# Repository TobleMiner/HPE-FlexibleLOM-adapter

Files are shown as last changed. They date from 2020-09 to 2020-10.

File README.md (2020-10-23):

HPE FlexibleLOM to PCIe adapter
===============================

This PCB is an adapter that allows using HPE FlexibleLOM cards in normal
PCIe x8 slots.

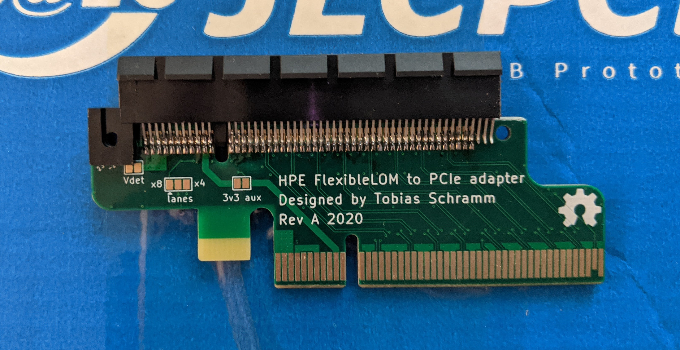
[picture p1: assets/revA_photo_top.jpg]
PCB top


# Ordering

Make sure to order this PCB with ENIG finish and beveled edges. Else contact
might be poor or your PCIe slots could be damaged.  
When ordering through JLC I'd recommend enabling the "Impedance" option and
sticking to the default JLC7628 stackup during ordering.

# Assembly

The board requires just a stradle mount PCIe x8 connector to be fitted.
You can get it at LCSC: [C404097](https://lcsc.com/product-detail/Card-Edge-Connectors_UMAX-3126-10102T_C404097.html)

# Mechanical mounting

This board has been designed to bring the front FlexibleLOM mounting hole as
close as possible to the PCIe bracket retention screw on a full size PCIe slot.
You can use a small angled metal piece or a even a 3d printed one to mount the
card into place.

# Jumpers

This adapter cards has several jumpers. You should not need to touch them, however
the following sections will explain their purpose.

## PERST

This jumper selects where the PCIe reset signal is routed. By default it is routed
to A1 on the FlexibleLOM slot. I believe this to be the PCIe reset signal. However,
there is also another pin on the connector, A14 which behaves similarly to A1.  
Testing has shown that the cards does not always enumerate properly when using A14
as PCIe reset.  
The two resistor footprints next to this jumper can be populated in case you are
having issues with floating resets on the cards resulting in spurious resets. I
have not encountered any such issues.

## Vdet

The Vdet jumper bridges +12V to pin B1 on the FlexibleLOM slot. I assume B1 to be
some sort of voltage detection pin since it is routed very differently from all
other +12V power signals on the card.

## 3v3 aux

The 3v3 aux jumper connects what I think is the auxiliary 3v3 volt voltage supply
on the FlexibleLOM slot to the auxiliary 3v3 supply of the PCIe connector. Most
cards I've seen do not use this voltage rail. However I assume there might be some
that utilize it for WOL capability.

## lanes

This jumper controls which PRSNT2 pin is bridged to PRSNT1. It defaults to PRSNT2
for 8x cards since that is the maximum number of lanes on a FlexibleLOM slot. You
can try setting this jumper to 4x if you are having issues with card detection.  
However, a lot of modern devices tend to ignore the PRSNT2 line and rely solely on
detecting the lane transmitters/receivers. Thus this setting will be irrelevant for
most devices.

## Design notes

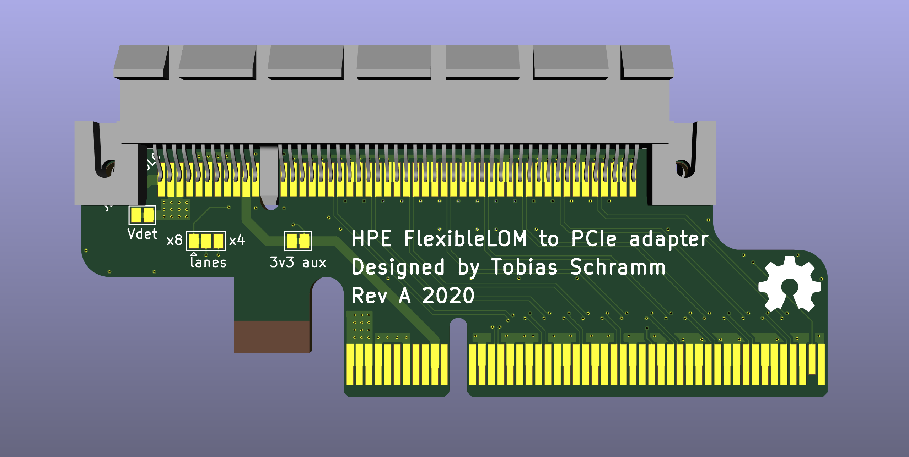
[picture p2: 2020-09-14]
assets/HPE_FlexibleLOM_adapter_x8_top.png

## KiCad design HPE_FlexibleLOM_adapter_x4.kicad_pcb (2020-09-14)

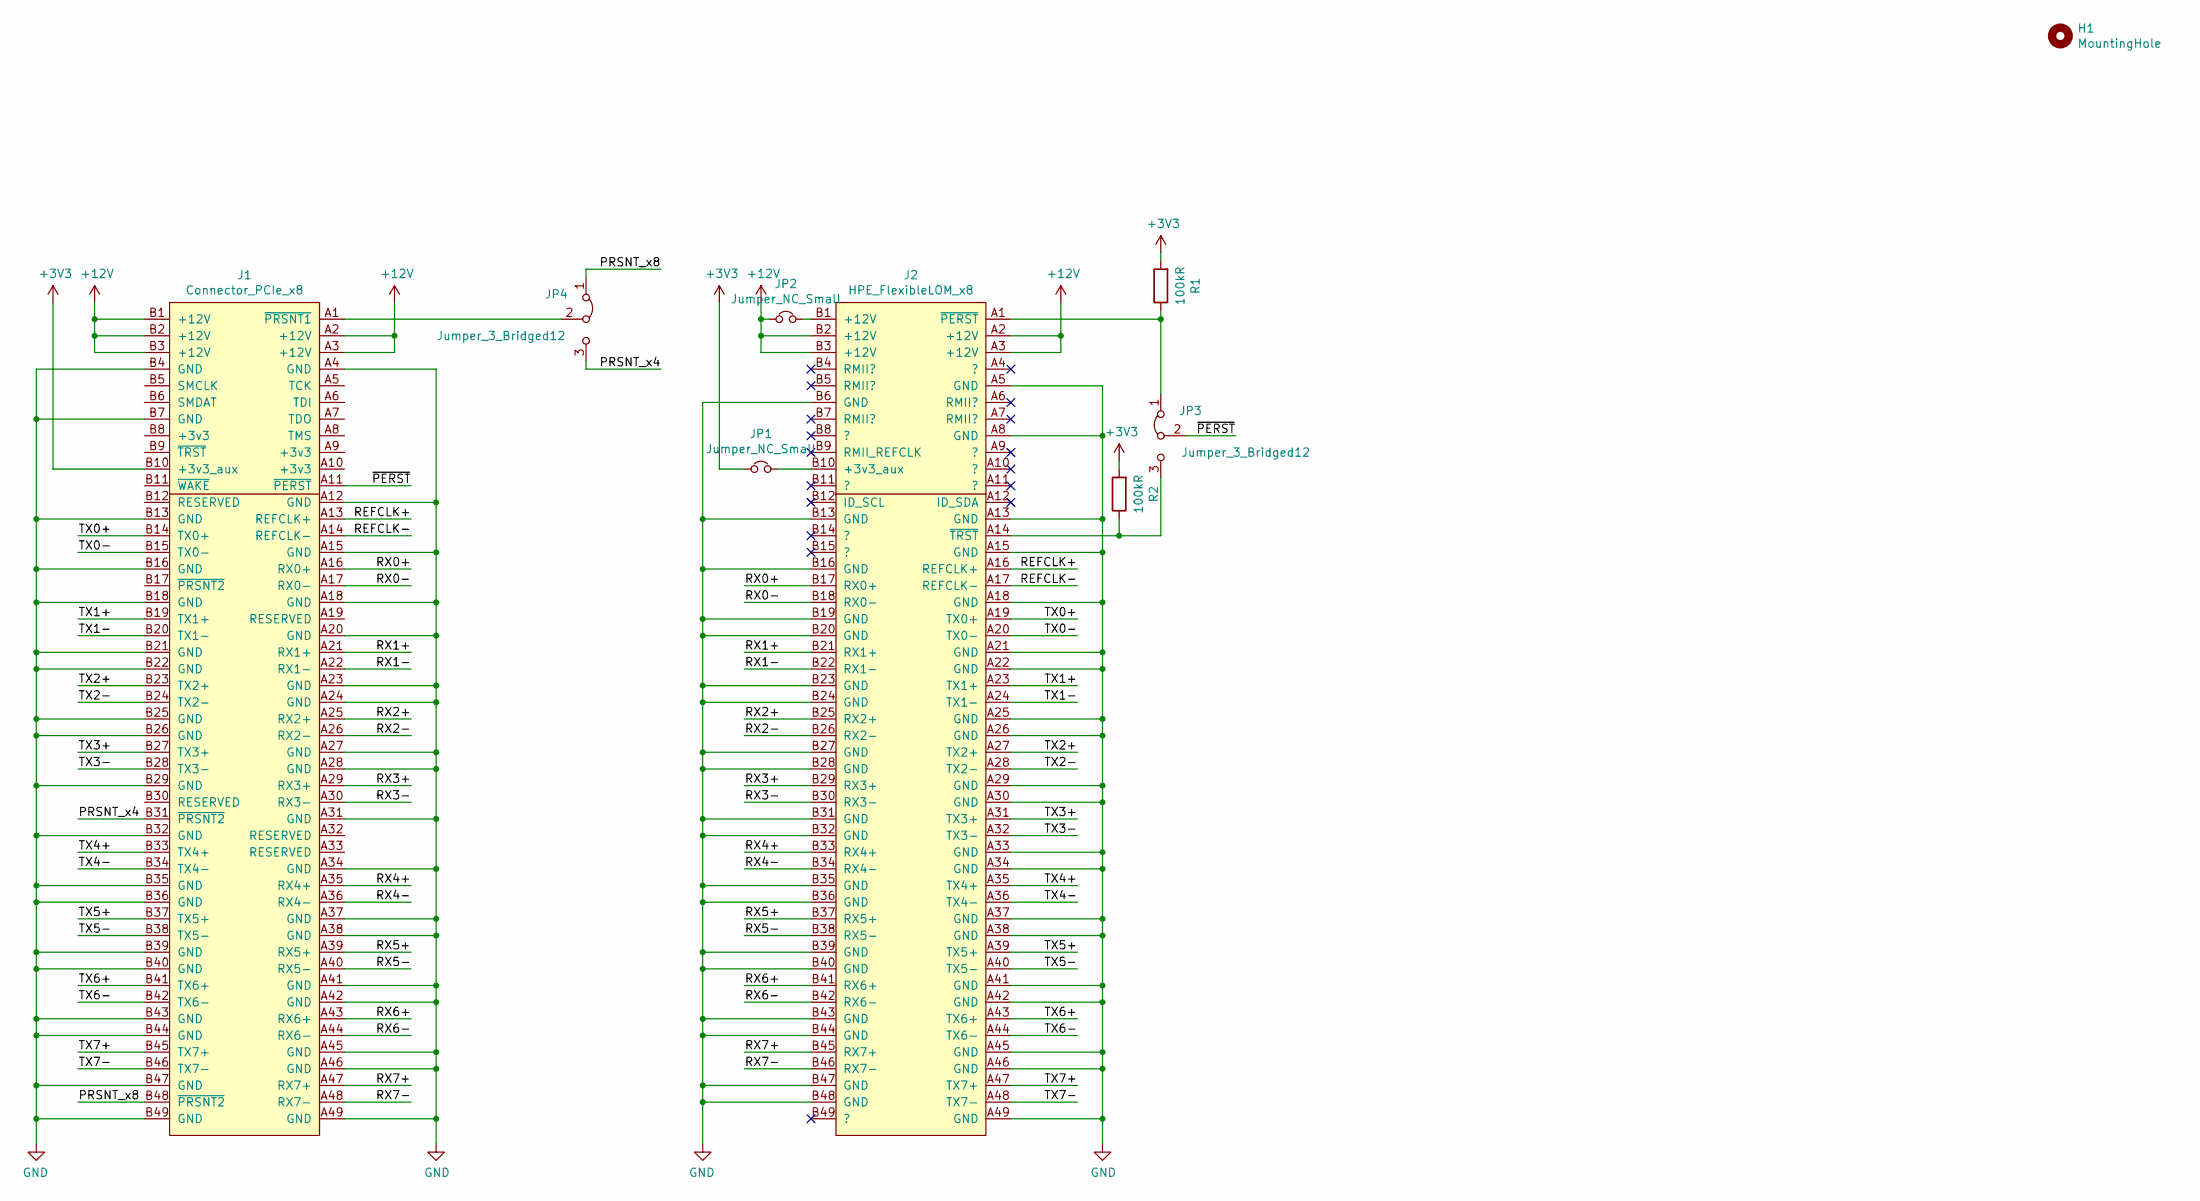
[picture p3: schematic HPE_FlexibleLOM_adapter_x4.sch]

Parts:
H1: MountingHole; OSHW-Symbol_6.7x6mm_SilkScreen
J1: Connector_PCIe_x8; BUS_PCIexpress_x8
J2: HPE_FlexibleLOM_x8; UMAX_3126-10102T_PCIe_x8_edge_launch
JP1, JP2: Jumper_NC_Small; SolderJumper-2_P1.3mm_Bridged_Pad1.0x1.5mm
JP3, JP4: Jumper_3_Bridged12; SolderJumper-3_P1.3mm_Bridged12_Pad1.0x1.5mm
R1, R2: 100kR; R_0402_1005Metric

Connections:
+3V3: J1.B10 (+3v3_aux), JP1.1, R1.2, R2.2
+12V: J1.A2 (+12V), J1.A3 (+12V), J1.B1 (+12V), J1.B2 (+12V), J1.B3 (+12V), J2.A2 (+12V), J2.A3 (+12V), J2.B2 (+12V), J2.B3 (+12V), JP2.1
/PRSNT_x4: J1.B31 (~PRSNT2), JP4.3 (B)
/PRSNT_x8: J1.B48 (~PRSNT2), JP4.1 (A)
/REFCLK+: J1.A13 (REFCLK+), J2.A16 (REFCLK+)
/REFCLK-: J1.A14 (REFCLK-), J2.A17 (REFCLK-)
/RX0+: J1.A16 (RX0+), J2.B17 (RX0+)
/RX0-: J1.A17 (RX0-), J2.B18 (RX0-)
/RX1+: J1.A21 (RX1+), J2.B21 (RX1+)
/RX1-: J1.A22 (RX1-), J2.B22 (RX1-)
/RX2+: J1.A25 (RX2+), J2.B25 (RX2+)
/RX2-: J1.A26 (RX2-), J2.B26 (RX2-)
/RX3+: J1.A29 (RX3+), J2.B29 (RX3+)
/RX3-: J1.A30 (RX3-), J2.B30 (RX3-)
/RX4+: J1.A35 (RX4+), J2.B33 (RX4+)
/RX4-: J1.A36 (RX4-), J2.B34 (RX4-)
/RX5+: J1.A39 (RX5+), J2.B37 (RX5+)
/RX5-: J1.A40 (RX5-), J2.B38 (RX5-)
/RX6+: J1.A43 (RX6+), J2.B41 (RX6+)
/RX6-: J1.A44 (RX6-), J2.B42 (RX6-)
/RX7+: J1.A47 (RX7+), J2.B45 (RX7+)
/RX7-: J1.A48 (RX7-), J2.B46 (RX7-)
/TX0+: J1.B14 (TX0+), J2.A19 (TX0+)
/TX0-: J1.B15 (TX0-), J2.A20 (TX0-)
/TX1+: J1.B19 (TX1+), J2.A23 (TX1+)
/TX1-: J1.B20 (TX1-), J2.A24 (TX1-)
/TX2+: J1.B23 (TX2+), J2.A27 (TX2+)
/TX2-: J1.B24 (TX2-), J2.A28 (TX2-)
/TX3+: J1.B27 (TX3+), J2.A31 (TX3+)
/TX3-: J1.B28 (TX3-), J2.A32 (TX3-)
/TX4+: J1.B33 (TX4+), J2.A35 (TX4+)
/TX4-: J1.B34 (TX4-), J2.A36 (TX4-)
/TX5+: J1.B37 (TX5+), J2.A39 (TX5+)
/TX5-: J1.B38 (TX5-), J2.A40 (TX5-)
/TX6+: J1.B41 (TX6+), J2.A43 (TX6+)
/TX6-: J1.B42 (TX6-), J2.A44 (TX6-)
/TX7+: J1.B45 (TX7+), J2.A47 (TX7+)
/TX7-: J1.B46 (TX7-), J2.A48 (TX7-)
/~PERST: J1.A11 (~PERST), JP3.2 (C)
GND: J1.A4 (GND), J1.A12 (GND), J1.A15 (GND), J1.A18 (GND), J1.A20 (GND), J1.A23 (GND), J1.A24 (GND), J1.A27 (GND), J1.A28 (GND), J1.A31 (GND), J1.A34 (GND), J1.A37 (GND), J1.A38 (GND), J1.A41 (GND), J1.A42 (GND), J1.A45 (GND), J1.A46 (GND), J1.A49 (GND), J1.B4 (GND), J1.B7 (GND), J1.B13 (GND), J1.B16 (GND), J1.B18 (GND), J1.B21 (GND), J1.B22 (GND), J1.B25 (GND), J1.B26 (GND), J1.B29 (GND), J1.B32 (GND), J1.B35 (GND), J1.B36 (GND), J1.B39 (GND), J1.B40 (GND), J1.B43 (GND), J1.B44 (GND), J1.B47 (GND), J1.B49 (GND), J2.A5 (GND), J2.A8 (GND), J2.A13 (GND), J2.A15 (GND), J2.A18 (GND), J2.A21 (GND), J2.A22 (GND), J2.A25 (GND), J2.A26 (GND), J2.A29 (GND), J2.A30 (GND), J2.A33 (GND), J2.A34 (GND), J2.A37 (GND), J2.A38 (GND), J2.A41 (GND), J2.A42 (GND), J2.A45 (GND), J2.A46 (GND), J2.A49 (GND), J2.B6 (GND), J2.B13 (GND), J2.B16 (GND), J2.B19 (GND), J2.B20 (GND), J2.B23 (GND), J2.B24 (GND), J2.B27 (GND), J2.B28 (GND), J2.B31 (GND), J2.B32 (GND), J2.B35 (GND), J2.B36 (GND), J2.B39 (GND), J2.B40 (GND), J2.B43 (GND), J2.B44 (GND), J2.B47 (GND), J2.B48 (GND)
unnamed: J1.A1 (~PRSNT1), JP4.2 (C)
unnamed: J2.A1 (~PERST), JP3.1 (A), R1.1
unnamed: J2.A14 (~TRST), JP3.3 (B), R2.1
unnamed: J2.B1 (+12V), JP2.2
unnamed: J2.B10 (+3v3_aux), JP1.2

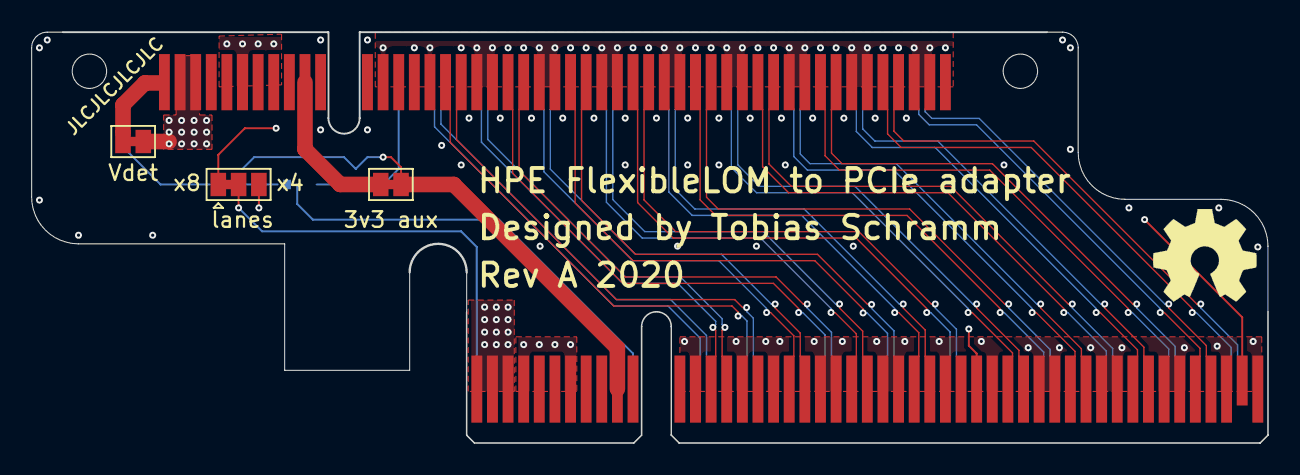
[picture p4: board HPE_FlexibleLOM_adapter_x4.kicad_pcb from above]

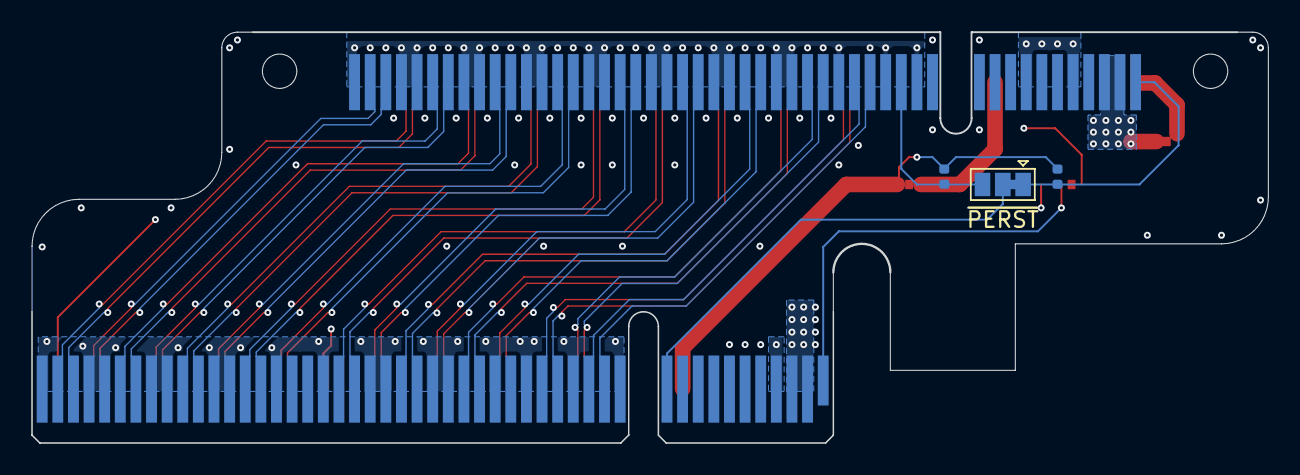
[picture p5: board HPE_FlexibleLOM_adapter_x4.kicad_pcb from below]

Board: 4 copper layers, 79.2 x 26.3 mm, 9 parts (3 on the bottom side), 45 nets.

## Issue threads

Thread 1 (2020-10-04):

JLCPCB caan not produce the chamfered edges

MarcSN311, 2020-10-04:
I just tried to order the PCBs from JLCPCB. They wont produce the chamfered edges because the minimum required board size for the chaamfer is 50mm.
Maybe you should add that to the Readme to make the ordering process smoother.

DanielG, 2020-10-04:
I also ordered some boards from JLC just now, but they seem to have accepted them for production without a hitch. Though you are right, their [docs](https://jlcpcb.com//quote/pcbOrderFaq/Gold%20Fingers) say "3. A board with a size of smaller than 5x5cm will be too small to be beveled.". Weird.

TobleMiner, 2020-10-04:
Interesting. I did not run into that issue.
I could panelize the boards, connecting two at the long non-beveled side. IIRC they can bevel opposing edges.

TobleMiner, 2020-10-04:
@MarcSN311
I've panelized two of the boards. Feel free to try uploading this file to JLC:
[fab_panel.zip](https://github.com/TobleMiner/HPE-FlexibleLOM-adapter/files/5323663/fab_panel.zip)

MarcSN311, 2020-10-04:
@DanielG they accepted my production files as well but then reached out to me to tell me they could not do it.
@TobleMiner Thanks, i'll give it a try.

TobleMiner, 2020-10-05:
@MarcSN311 Did JLC approve the files yet? I'd love to update the repo with a panelized version.

footlongC, 2020-10-07:
> @MarcSN311 Did JLC approve the files yet? I'd love to update the repo with a panelized version.

I was able to get an order in and approved yesterday. Shows in production now.

MarcSN311, 2020-10-07:
Sorry I'm a bit slow. I will inform you as soon as my production files are confirmed.

TobleMiner, 2020-10-08:
No worries. I'm not in a hurry. Just want to make sure you are keeping us all up to date :smile:

psc24, 2020-10-09:
I've had fab_panel.zip rejected because it had too many files; I assume this is the embedded fab_panel directory. Having removed that from the zip it seems to have been accepted.

neobenedict, 2020-10-13:
I was able to order revA.zip quantity 10 pieces without issue. It might be you weren't ordering a large enough quantity.

psc24, 2020-10-13:
Nope, I ordered 10 off as well. Based on experience so far, I think it's just as likely that there's little consistency in the checks JLC perform!

Hi Sir/ Madam, there are too many files in your zip file and we don’t know which file we should use, so could you please delete useless files in your Zip file?You can click ‘Replace file’ button to re-upload the file in your JLCPCB account page .Thanks.

TobleMiner, 2020-10-17:
Oops, the subdirectory is not supposed to be in that zip file. I've updated the zip file above again (actually final this time, I promise!) so JLC won't be confused by it anymore.

MarcSN311, 2020-10-20:
Just received my order!
I had the same problem with the duplicate files, but they did not complain about the chamfered edges anymore.
Sadly they did not produce the chamfered edges anyways -.-

neobenedict, 2020-10-20:
Same thing here, no chamfers, is it an issue?

MarcSN311, 2020-10-20:
I think the chafers are just nicer to your PCIe slots. I am just annoyed by thefact that they exchanged a bunch of messages with me about the chafer and in the end they did not produce it anyways.

laf0rge, 2020-10-21:
Indeed, the production run JLC did for me also silently disregarded the chamfered edges. I think with careful insertion into the slots it shouldn't be that much of a problem.  Aside from that, there's always the option to file the edges by hand, but FR4 dust is also not particularly healthy, to say the least...

kontakt, 2020-10-23:
I ordered 5x of the latest and got received 4, one did not survive fab. May be related to difficulty in chamfering.

MarcSN311, 2020-10-23:
@kontakt were the remaining 4 PCBs chamfered?

kontakt, 2020-10-23:
Yes, the four I received were chamfered.

TobleMiner, 2020-10-23:
@neobenedict It is not a particularly big issue. However it makes insertion easier and increases the lifetime of the PCIe slot.

jbaznik, 2020-12-31:
Is this order HPE FlexibleLOM to PCIe adapter from https://cart.jlcpcb.com by your notes for ordering:

[cart.jlcpcb.com-PCB Prototype amp PCB Fabrication Manufacturer - order - HPE-FlexibleLOM-adapter.pdf](https://github.com/TobleMiner/HPE-FlexibleLOM-adapter/files/5757713/cart.jlcpcb.com-PCB.Prototype.amp.PCB.Fabrication.Manufacturer.-.order.-.HPE-FlexibleLOM-adapter.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)

TobleMiner, 2021-01-01:
Other than that I'd suggest selecting "Specify a location"at the bottom of the page this order looks correctly configured to me.

the1cyrus, 2021-02-16:
How much did your order of 10 cost you? I'm trying to use oshpark

TobleMiner, 2021-02-16:
Depends on whether you want 10 boards or 10 adapters, since there are 2 adapters per board. With edge chamfer and ENIG the prices at JLC are:

5 boards: $20
10 boards: $25

Most of the price is a one-time fee for surface finish and edge chamfer.

the1cyrus, 2021-02-16:
> 10 boards or 10 adapters

The difference between the two are what? The gerber files you upload on the site? Boards are fab_panel.zip and adapters are revA.zip?

I tried uploading the fab_panel.zip and got a quote for $29.20 (qty 10) with the settings are shown on the pdf from jbaznik. That sound right or should i upload revA.zip and do the same settings from jbaznik?

TobleMiner, 2021-02-17:
Yes, the panel contains two adapter boards each. However, getting the panel made costs the same as ordering just single boards.

$29 sounds about right? Does that price include shipping? My previous numbers were probably e bit off since I guesstimated them from  Euros.

the1cyrus, 2021-02-17:
So the grand total is $44 with fab_panel.zip. The boards were $29 and shipping with Fedex was $15. I added gold fingers to try and reduce some oxidation over time but that was probably not needed (i didn't see a price increase with that option).  TobleMiner do you have a way to contact you outside this github issue?

TobleMiner, 2021-02-18:
@the1cyrus Sure, feel free to write me either DMs on Twitter (https://twitter.com/Toble_Miner) or contact me by E-Mail: tobleminer(at)gmail(dot)com

the1cyrus, 2021-02-18:
Just fyi for everyone.. JLCPCB charged me an extra $25 because I used the paneled boards (fab_panel.zip).
"Hi Sir/Madam,the special price is only for the single board and not for the panel board,so you may need to pay for an extra cost for it."

TobleMiner, 2021-02-18:
Unfortunately review is very inconsistent at JLC. This kind of stuff seems to depend heavily on who exactly reviews your gerber files. Not that I'd recommend this, but sometimes just cancelling the order and resubmitting it might work wonders.

CNC-at-Home, 2021-09-10:
Hi together, I've a question please, I ordered some of the pcbs from sysmocom.de and then I attached it with the LAN-Card (it's a HPE FlexFabric 10Gb 2-port 533FLR-T)  into the motherboard, but no reaction from Windows 10. Maybe is there a need to set jumpers or should it works out of the box, only soldering the pins. I've a second card for my Linux Server, but I will wait to build in until my question is answered. Thank you

Greetings
Olli

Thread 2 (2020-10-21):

extend Readme

MarcSN311, 2020-10-21:
Hi,
would be great if you could extend the readme a little bit.

From my limited testing I think the host PCIe slot needs to provide 3.3V, can you confirm that?

Could you describe in which cases the jumpers need to be changed?

TobleMiner, 2020-10-23:
Hi,

sure. I'm very open to ideas regarding a better README.

I'm not sure if the cards require 3.3V. On one of the SFP+ models I have the 3.3v rail is not connected to anything on the board. Might be that other cards need it though.

The jumpers were mostly there in case I messed up during reverse engineering.

I'll add a section to the README explaining what the different jumpers do.

MarcSN311, 2020-10-23:
I had one of the Mellanox ConnectX-3 single port SFP+ cards lying around. I just measured and found the 3.3V Rail is connected to a bunch of caps on the board.

A list of tested card with their requirements might be another useful addition to the Readme (or maybe the wiki?).

TobleMiner, 2020-10-23:
Think 8cc9fc21a973bd5b9cdf8be47b14b1373eb9ac02 should make this a lot clearer

TobleMiner, 2020-10-23:
@MarcSN311
> I just measured and found the 3.3V Rail is connected to a bunch of caps on the board.
Yeah, nvm. Did not remember this correctly. The 3v3 aux are connected on my card, too. Guess it might be to keep connectivity via NC-SI even when +12V is missing?

MarcSN311, 2020-10-25:
Thanks for the Readme update! I think this resolves the issue for me.

Closed 2020-10-25.

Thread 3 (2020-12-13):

Adapter confirmed working with HP 561FLR-T - we might want a compatibility list?

Aterfax, 2020-12-13:
I have installed a HP 701525-001 ETHERNET 10GB 2-PORT 561FLR-T ADAPTER 700699-B21 700697-001 today into my Windows 10 Machine and confirmed basic functions are working fully.

I may eventually do some performance testing but this is my only 10GB card installed so far.

Drivers can be downloaded here:  https://support.hpe.com/hpsc/swd/public/detail?swItemId=MTX_a3bc42166be146aea4156a05a9

Unzip the exe with 7zip into a folder, then update drivers on the below and point at the folder.

Screenshots below:
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

logan2611, 2020-12-27:
I can also confirm that these adapters (mostly) work with the 561FLR-T. Linux' ixgbe driver works with these out of the box.
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
I was able to get 9.38 Gb/s with iperf.

I'm not sure if I have defective ones or if the adapter isn't fully compatible but I have a few that do not work with various issues. Two don't have power and one hangs the BIOS during boot time. Most of them however work fine.

Aterfax, 2021-03-20:
Seems that the ixgbe driver may have issues as I cannot get connectivity over the 2nd ethernet port under Proxmox - this appears to be fine in Windows 10.

NishaYume, 2021-04-05:
Thats nice, im thinking to try it. Is the model 700699-B21 you tested with the rev a?

Aterfax, 2021-04-05:
>
>
> Seems that the ixgbe driver may have issues as I cannot get connectivity over the 2nd ethernet port under Proxmox - this appears to be fine in Windows 10.

I resolved this issue - Proxmox wasn't setting things on the CLI despite being set in the GUI.

All my adaptors are they rev a.

templehasfallen, 2021-06-18:
> I'm not sure if I have defective ones or if the adapter isn't fully compatible but I have a few that do not work with various issues. Two don't have power and one hangs the BIOS during boot time. Most of them however work fine.

I'm having a similar issue - only 3 out of 11 of my 561FLR-T cards seem to be working with the rev.A adapter - the others are not detected at all.

I cannot find any real differences between the cards, they seem to be identical. Also the cards heat up to the same degree as the working ones.

Any ideas?

LimesKey, 2023-09-28:
Works for me too! Thank you for the driver link, I spent way too long looking through HP’s website. Now time to try to use it on Linux…

jimmycaille, 2023-10-05:
I have just purchased one on Ebay.
I will let you know how it works for me on a more recent Asus x570-pro and Windows 10 (if I don't forget...).
The listing is "701525-001 700699-B21 700697-001" So I don't know wich one I will get...

_To be continued_

Pet0203, 2023-10-08:
Also running a 701525-001. Interestingly it prevents my Dell T3600 from booting but it runs fine and gets detected in a newer machine. Very weird how it doesn't want to boot, while the card is getting power and link lamps turn on.

wildboyfire, 2023-11-07:
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

Hi, i did the same exact thing and i use x570 platform too but i can't get it to work. The 10Gbe card only gets recognised as ethernet controller in device manager, under other devices, only when i turn off the psu for a while and then start it up as normal.When i reboot the system the card will not show up in device manager. When i install the drivers (when it gets recognised) the card will vanish from device manager. Any suggestions?

Aterfax, 2023-11-07:
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

A hot boot causing issues suggests the machine might not be "turning off" the card properly during shutdown and it gets stuck in some inaccessible state preserved by remaining powered (which is flushed by actually being powered down.)

I'd double check the correct drivers are installed, try toggling any card power saving features off and disable Windows fast boot if it is enabled (causes hibernation shenanigans) and see if that helps.

wildboyfire, 2023-11-07:
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

Oh okay, tomorrow when i wake up i'll try that, and let you know. Thank you for your time.

jimmycaille, 2023-11-08:
Hi guys, please don't quote the previous message if you respond to it directly anyway or don't refer to one of its part only.

Anyway, I have received the hardware and installed it without issues other than one screw was too small to mount the card to the adapter so I used some tape. At the end I paid $14 for the card and $8 for the adapter.

I have Windows 10 with the latest updates, without hibernation and fastboot enabled, with the driver given by the top comment.
I didn't encounter issues after a shutdown but haven't tried any reboot yet. I can report back in a few days about my experience.

Pet0203, 2023-11-08:
There is firmware that you may need to flash to the 561FLR. If you can't get it detected in Windows I would suggest that you use a bootable Linux distro to flash the new firmware, it may improve stuff.

I'm however still not having any luck getting the OROM to boot, I'm just stuck with a flashing cursor when BIOS tries to load it. Seems it isn't compatible with my board.

jimmycaille, 2023-11-08:
> There is firmware that you may need to flash to the 561FLR. If you can't get it detected in Windows I would suggest that you use a bootable Linux distro to flash the new firmware, it may improve stuff.
I have found this post seemingly well detailed on how to update the board firmware : [servethehome.com - 10 and 40 Gb networking on the cheap ($5 - $10)](https://forums.servethehome.com/index.php?threads/10-and-40-gb-networking-on-the-cheap-5-10.30394/).

> I'm however still not having any luck getting the OROM to boot, I'm just stuck with a flashing cursor when BIOS tries to load it. Seems it isn't compatible with my board.
You could try to manually put the PCIE port to 8x in the BIOS

wildboyfire, 2023-11-08:
BIG DISCLAIMER: my english is bad.
Today i 've tried a bunch of things:
First of all i've tried installing a bunch of different drivers for the intel x540 chip that you can find on their website, but nothing changed. Then i've tried to reinstall the intel complete package driver, but when the "installing drivers" windows pop up during the installation it just says that it's just installing drivers for my intel gigabit controller on the mobo. Before installing the x540 drivers, that window also said that it was installing the HP 561FLR-T 10Gbe drivers but now it doesn't; moreover installing any kind of drivers doesn't make them disappear anymore, they do only when i reboot (also while fastboot and ibernation are disabled).
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

Another thing i did was going into the bios settings and change the pcie to gen 2.0 and 3.0 but in both cases nothing changed. I've also tried mounting it on a intel 6th gen build but it doesn't get recognised at all, even if i shut down the psu for a while. i have now messaged the ebay vendor i got the flexiblelom to pcie adapter(see picture) from and he said that he will send me another adapter; The reason behind messaging him is that i've read this article :
https://blog.naver.com/PostView.naver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
and he says that the adapter is just plug and play, so i think my adapter is faulty and i'll test the new one when it arrives. There's also the possibility that the hp adapter is faulty and in that case i'm screwed.
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
Given this informations does anyone have a clue of what the problem might be?

betrieb, 2023-11-29:
I bought 3 of the 701525-001 561FLR-T cards off ebay. I have tried them on 3 different motherboards with no luck. Herewith the motherboards and the symptoms:
MSI X470 GAMING PRO (MS-7B79): I tried all three of them in different 16x slots. Cards are not detected. They don't show up in Bios or Device Manager. I tried multiple restarts with no luck. When I plug in an ethernet cable to my switch none of the status indicator LEDs light up on the card's side.
Gigbyte GA-Z77-D3H: Plugged into any of the 16x slots. The PC does not post. It just reboots itself after a couple of seconds.
TB250-BTC Ver 6.2: Plugged into the only 16x slot. It just beeps upon powering it on and re-starts itself after about 20 seconds and beeps again.

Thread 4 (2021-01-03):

Modification required for Broadcom based FlexLOM cards (530/533FLR)

halmartin, 2021-01-03:
The HPE 530FLR-SFP+ and 533FLR-T cards are based on the Broadcom BCM57810. These cards do not work with the adapter without modification.

The [KCORES FlexibleLOM Adapter](https://github.com/KCORES/KCORES-FlexibleLOM-Adapter) appears to have a more accurate pinout of the FlexLOM connector:
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

The following modifications to the adapter make it compatible with the Broadcom-based FlexibleLOM cards:

1. Cut the trace between Vdet (to make pin B1 N/C)
1. Cut the trace connecting PERST to pin A1 (between the center/right solder pads)
1. Bridge the PERST left/center solder pads so PERST is connected to A14
1. Bridge 3.3V pad to pin A1
1. Connect 3.3V pad to A10/A11
1. Bridge GND between pins A4/A5/A6/A7/A8

With the above changes, the 533FLR-T adapter is working for me: [lspci output](https://gist.github.com/halmartin/2a91d8f7cbb75cd52c16e5f498eec78d)

----

Here is an annotated photo of the modifications required:
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

----

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
(The additional wire is to connect nWAKE)

TobleMiner, 2021-01-03:
Cool! I'll prepare a RevB for testing. Many thanks for bringing this to my attention.

halmartin, 2021-01-03:
For the pins requiring +3.3V, I bridged from +3.3V_AUX because it was easy and exposed on RevA, but I'm not sure if this is the "correct" way. KCORES are using +3.3V from pins B8/A9/A10 in their adapter.

I don't know enough KiCad to modify the adapter in this way, sorry.

TobleMiner, 2021-01-03:
Hey, no worries. I'm not entirely sure about the 3.3V domains either. I wil derive PWROK from the main 3.3V rail since it is likely intended to be a power good signal for the 12V rail. To me another worry are the software deifned pins (SDP). I'm not entirely sure what they are doing. To me it seems a bit risky to pull them to 3.3V that hard.
Unfortunately I don't have access to any HP servers with a FlexibleLOM slot. Thus I can't verify whether the KCORES adapter matches what HP is doing.

obedouet, 2021-01-05:
Hello,

I tested successfully the modification with a HP 530FLR-SFP+, without such hack, card was not visible through lspci. I did not add the additional wire. Thanks for the trick !

MGX3D, 2021-01-18:
Thanks Tobias for the adapter and Hal for the mods! I wanted to confirm that revision A didn't work for me, but with the mods above I got 533FLR-T working. I haven't benchmarked it at 10GbE yet, but lspci/LnkSta says it's 5GT/s x8, ssh/scp works fine over it, etc.

However, the adapter still does not work for 561FLR-T (Intel X540), the only mod I didn't do is the nWAKE one, not sure if required?

One other suggestion I have for rev B is to reduce the copper plane that gets exposed when beveled: this might also be the reason JLCPCB doesn't bevel the PCBs. They didn't for me either, I did it manually and ended up exposing this plane and managed to kill a motherboard with it. I did notice the copper was exposed  even though bevel was very light compared to other PCIe cards, but I figured I'd be safe once inserted because it should sit under the PCIe contacts in the connector, but I forgot to disconnect the PSU (rookie mistake) so the motherboard powered on while I was inserting the adapter and that was that! Luckily it was not a super expensive mb.
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

TobleMiner, 2021-01-19:
Hi!

I'm super sorry to hear that. Retracting the GND plane a bit is something I should have done in the initial design. I've just redesigned the adapter, fixing both the pin assignments for the Flexible LOM slot (I've left out the SPD pins for now though) and the GND plane in the beveled area: https://github.com/TobleMiner/HPE-FlexibleLOM-adapter/tree/revb-untested

The design is not tested yet, but I've ordered it yesterday. So it should be here within the next two weeks or so.

MGX3D, 2021-01-24:
Small update, I think I figured out why the rev A PCB (without any mods) worked with 561FLR-T for others but not for me initially: the reason seems to be as simple as using a PCIe powered video card vs one with separate power from PSU. I guess it has to do with total power draw of the two cards or possible mb quirks? Anyway, wanted to confirm that 561FLR-T without mods does work for me as well (when using a beefier video card with separate power connector).

DrivebyCoding, 2021-01-31:
> Unfortunately I don't have access to any HP servers with a FlexibleLOM slot. Thus I can't verify whether the KCORES adapter matches what HP is doing

I have a bunch of machines with FlexLOM and 544FLR. Anything in particular you want tested? Bricking a few MBs or HBAs is not a problem.

halmartin, 2021-02-05:
@obedouet Did you add GND on pins B9 and B11?

I purchased a 530FLR-SFP+ that draws 2W and does not enumerate on the PCIe bus without grounding pins B9 and B11. Grounding pins B9 and B11 results in the card consuming 6W and successfully initializing.

TobleMiner, 2021-02-05:
@halmartin Are you sure grounding B9 is required? According to the information I got that should only be TX enable for NC-SI.

halmartin, 2021-02-05:
@TobleMiner I'm not certain, I have two versions of the modified adapter, one with B9/B11 connected to GND, and the other with the modifications I describe above.

The 530FLR-SFP+ I have does not work in the adapter that does not have B9/B11 grounded. Unfortunately my soldering iron has broken, so I cannot desolder connections to test if only B11 is required. I can test this when my new soldering iron arrives.

obedouet, 2021-02-07:
> @obedouet Did you add GND on pins B9 and B11?
>
> I purchased a 530FLR-SFP+ that draws 2W and does not enumerate on the PCIe bus without grounding pins B9 and B11. Grounding pins B9 and B11 results in the card consuming 6W and successfully initializing.

Hello, I did not modify B9 and B11. I've only applied your steps 1-6. The card is working in a ESX since my comment (1/5) without any issue, really stable.

dmg244, 2021-02-09:
/gerbers//revB_panel.zip have revA files inside.

TobleMiner, 2021-02-14:
Oops, sorry for that. I've just updated the branch to now feature the RevB gerbers in that file.

dmg244, 2021-02-15:
@TobleMiner Can you make revision C with the grounding of lines B9, B11, A4, A6, A7 and the connected WAKE line - A9 LOM to B11 PCI-E, A10 and A11 to +3.3V (all lines like KCORES design)? I want try to order this design for test. Why you use only +3.3V_AUX and don't use +3.3V?

Nooby1, 2021-02-16:
I have ordered the RevB, I have some 530FLR-SFP+ (647581-B21) and QDR 544+FLR-QSFP (764286-B21)

I will update you in about two weeks

Does anyone know if these cards are confirmed working in rev A?

TobleMiner, 2021-02-16:
@dmg244
> @TobleMiner Can you make revision C with the grounding of lines B9, B11, A4, A6, A7 and the connected WAKE line - A9 LOM to B11 PCI-E, A10 and A11 to +3.3V (all lines like KCORES design)? want try to order this design for test

Sure, will do. I don't feel that comfortable pulling the SDP pins that hard, but at least for a test it should be fine.

> Why you use only +3.3V_AUX and don't use +3.3V?
By mistake. PWROK shoudl have been connected to the 3v3 power rail. However, I think B10 is supposed to be +3v3_aux to allow NC-SI to work even during system shutdown.

TobleMiner, 2021-02-16:
@dmg244 Here you go: https://github.com/TobleMiner/HPE-FlexibleLOM-adapter/blob/revc-experimental/gerbers/revC_panel.zip

Think that should cover everything you might want to test. I've made sure to expose a good lenght of trace to any of the pins where we are not sure whether they are required for cards to enumerate or not. Feel free to experiment with cutting any of those traces and pulling them high/low or leave them floating :)

dmg244, 2021-02-16:
Thank you!
Already ordered from e-bay
2pcs HP 647579-001 649869-001 2-Port 530FLR SFP+ 10Gbps Ethernet Adapter
2pcs HPE 669281-001 Ethernet 560FLR-SFP+ 10GB 2-Ports PCI Express 2.0 x8 Adapter
HP 4-Port 684208-B21 629135-B21 634025-001 Ethernet 1Gb 331FLR Adapter

and connectors for testing.

JLCPCB will be produced PCB from 19 Feb

the1cyrus, 2021-03-04:
@dmg244 good luck with your testing. looking forward to seeing the results.

Digifreakl, 2021-03-12:
> I have ordered the RevB, I have some 530FLR-SFP+ (647581-B21) and QDR 544+FLR-QSFP (764286-B21)
>

I also bought some 530FLR-SFP+ (647581-B21), do you have any update?

dmg244, 2021-03-13:
Hello! Thank you for you attention!

Latest news )))

Already received:
2pcs HPE 669281-001 Ethernet 560FLR-SFP+ 10GB 2-Ports PCI Express 2.0 x8 Adapter
2pcs HPE AJ838A LC/LC FC 30m Multi-mode OM3 Cable (491028-001)

still waiting PCB's and connectors.

Also still waiting:
2pcs HP 647579-001 649869-001 2-Port 530FLR SFP+ 10Gbps Ethernet Adapter
1pcs HP 4-Port 684208-B21 629135-B21 634025-001 Ethernet 1Gb 331FLR Adapter
2pcs Intel E10GSFPSR FTLX8571D3BCV-IT E65689-001 SFP+ Transceiver For X520-DA2/SR2
2pcs JD092B HPE X130 10G SFP+SR LC FTLX8571D3BCL-HZ 850nm for 5900AF

Nooby1, 2021-03-20:
My PCBs arrived today. I got some soldered up and can confirm the revB worked with the 40gbe FLOM card QDR 544+FLR-QSFP (764286-B21)

I purchased 100 PCBs as the cost was not really much more than 20 from JLPCB due to the paneling of the design (required for edge chamfering with no extra cost)  If anyone would like to buy some PCBS or completed cards off me do let me know.

halmartin, 2021-03-20:
@Nooby1 Are you in the EU? I'd be interested in buying some PCBs from you.

Nooby1, 2021-03-20:
>
>
> @Nooby1 Are you in the EU? I'd be interested in buying some PCBs from you

Uk, and sure happy to sell up to 80 of them. I dont know the best way to share contact details on here however.

halmartin, 2021-03-20:
Can you email me? <username> (at) gmail

Rainfey, 2021-03-24:
@Nooby1 Is this offer still on the table?
Buying is preferable to waiting for shipping.

Regarding all the other adapters you ordered, have you managed to confirm if revB works with the 647579-001 model?

Nooby1, 2021-03-25:
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

Yes I still have pcb and completed models avalable, not tested with anything but connectx3 pro currently. Could test with 530flr in future

Rainfey, 2021-03-26:
@Nooby1 I have added you to a project with my email address in the description - shame about github's lack of social features.
Drop me a line when you are able.

dmg244, 2021-03-31:
Received all components.
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
I may confirm that adapter ver.C working with:

**HPE 669281-001 Ethernet 560FLR-SFP+ 10GB 2-Ports PCI Express 2.0 x8 Adapter**
```
#lspci
02:00.0 Ethernet controller: Intel Corporation 82599ES 10-Gigabit SFI/SFP+ Network Connection (rev 01)
02:00.1 Ethernet controller: Intel Corporation 82599ES 10-Gigabit SFI/SFP+ Network Connection (rev 01)
```

**HP 647579-001 649869-001 2-Port 530FLR SFP+ 10Gbps Ethernet Adapter**
```
#lspci
02:00.0 Ethernet controller: Broadcom Inc. and subsidiaries NetXtreme II BCM57810 10 Gigabit Ethernet (rev 10)
02:00.1 Ethernet controller: Broadcom Inc. and subsidiaries NetXtreme II BCM57810 10 Gigabit Ethernet (rev 10)
```

**HP 4-Port 684208-B21 629135-B21 634025-001 Ethernet 1Gb 331FLR Adapter**
```
#lspci
02:00.0 Ethernet controller: Broadcom Inc. and subsidiaries NetXtreme BCM5719 Gigabit Ethernet PCIe (rev 01)
02:00.1 Ethernet controller: Broadcom Inc. and subsidiaries NetXtreme BCM5719 Gigabit Ethernet PCIe (rev 01)
02:00.2 Ethernet controller: Broadcom Inc. and subsidiaries NetXtreme BCM5719 Gigabit Ethernet PCIe (rev 01)
02:00.3 Ethernet controller: Broadcom Inc. and subsidiaries NetXtreme BCM5719 Gigabit Ethernet PCIe (rev 01)
```

Rainfey, 2021-04-04:
Tried a 530FLR-SFP+ (649869-001) on a rev b board with no success.
I noted the following after making modifications to the adapter (modifications made in succession without undoing previous mods):
1) Grounding B9, B11 - No effect
2) Grounding A4, A6, A7 - No effect
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

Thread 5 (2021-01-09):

Alternative parts for PCIe connector

jairov4, 2021-01-09:
Guys can you point some alternative parts for PCIe connector?, Im in Colombia and find where to build the PCB from gerbers looks feasible. However, I dont know how to locate a compatible part from other popular vendors like DigiKey, Arrow, Mouser or even AliExpress.
Some sample links would much appreciated.

TobleMiner, 2021-01-19:
Hi! Sorry, I was a bit busy over the last few days.

As far as I can tell G630H9812248EU from Amphenol should be compatible. It is available both at Mouser and DigiKey.

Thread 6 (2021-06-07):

Rev B Tested and Working

Nawor3565, 2021-06-07:
Just wanted to let you know that I ordered and assembled two of the Rev B boards, and they worked perfectly! Now enjoying 10Gbit with my NAS setup.

delacor, 2021-06-14:
The rev. C in #4 is also working perfectly for me with a HP 530FLR. :)

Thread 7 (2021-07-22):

Single Board for Rev C

mlc130104, 2021-07-22:
Hello,

Would you like to release a single board design for rev C (like rev A) so that we may make use of 5 monthly free sample quotas from JLC?

Tried removing the jigsaws myself but in vain as I am total new to PCB software.

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

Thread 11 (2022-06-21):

Add attachment bracket STL / freecad files

Dantali0n, 2022-06-21:
Hello I have created a tiny simple bracket to hold the adapters in place, Figured you mind want to add them to assets and refer to them in the README.

I can create a pull request that does this if that's easier for you but didn't as this gives you the opportunity to use your own file structure and wording.

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

[bracket-hp-366-flr-network-card.zip](https://github.com/TobleMiner/HPE-FlexibleLOM-adapter/files/8946841/bracket-hp-366-flr-network-card.zip)

Screw holes are loosely sized so no threading as that is taken care of by the holes it will bind to themselves. Its aimed as a one size fits all solution rather than creating a very tight tolerance.

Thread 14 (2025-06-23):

Please explain the pinout difference between flexlom and regular pcie ?

shodanx2, 2025-06-23:
Hi,

Could you explain what is going on with this adapter ?

What is HP doing with this "flexLOM" unstandard that makes it incompatible with regular pcie slots ?

Are all the pins just shifted ?

I tried inserting one of these cards into a regular pcie slot.
While it goes in without issues, the PC will simply not boot, emitting series of beeps that sort of sounds like a "no video card error"

thanks !

PS I suggest you add this explanation to the readme !

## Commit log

2020-09-14 Do layout
    [HPE_FlexibleLOM_adapter_x4.kicad_pcb, HPE_FlexibleLOM_adapter_x4.sch]
2020-09-14 Some more GND via stitching
    [HPE_FlexibleLOM_adapter_x4.kicad_pcb]
2020-09-14 Add OSHW markings
    [HPE_FlexibleLOM_adapter_x4.kicad_pcb, HPE_FlexibleLOM_adapter_x4.sch]
2020-09-14 Add exclusion zone to PCI plugin-preventor thingy
    [HPE_FlexibleLOM_adapter_x4.kicad_pcb]
2020-09-14 Reverse engineer some more FlexibleLOM signals
    [HPE_FlexibleLOM_adapter_x4.kicad_pcb, HPE_FlexibleLOM_adapter_x4.sch]
2020-09-14 Add NC symbol to B49
    [HPE_FlexibleLOM_adapter_x4.kicad_pcb, HPE_FlexibleLOM_adapter_x4.sch]
2020-09-14 add revA gerbers
2020-09-14 Add section on mechanical assembly details
